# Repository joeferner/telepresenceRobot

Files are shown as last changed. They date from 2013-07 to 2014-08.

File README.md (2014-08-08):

Telepresence Robot
==================

After seeing a commercial for a Telepresence robot on TV, I knew I wanted to play with one, but after looking at prices I didn't want to pay for one.

I used an Android Nexus 7 tablet for the video conferencing. A custom PCB with an STM32 ARM processor and an FTDI USB chip to connect the Android tablet with the motors.

[Schematic](https://github.com/joeferner/telepresenceRobot/blob/master/hardware/main.pdf?raw=true)

Video
-----

YouTube (http://www.youtube.com/watch?v=nxQw_-PgoPo)

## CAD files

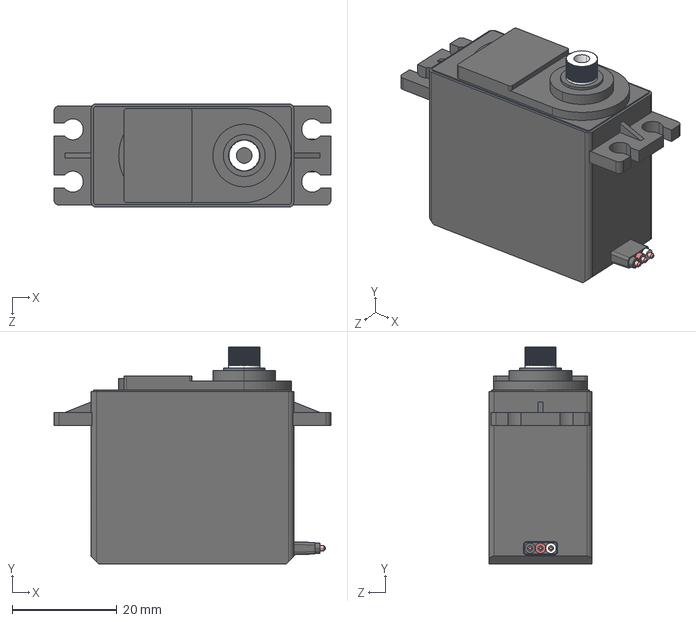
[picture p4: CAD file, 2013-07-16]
mechanical/Servo.STEP
53.0 x 41.5 x 19.8 mm

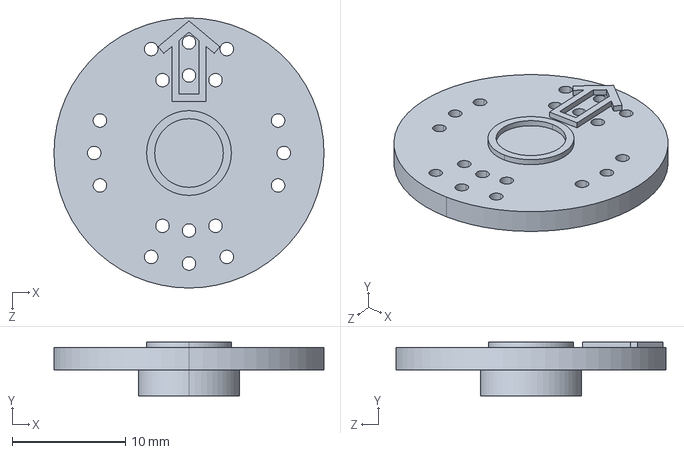
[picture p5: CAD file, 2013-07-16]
mechanical/Servo-Horn.STEP
23.9 x 4.78 x 23.9 mm

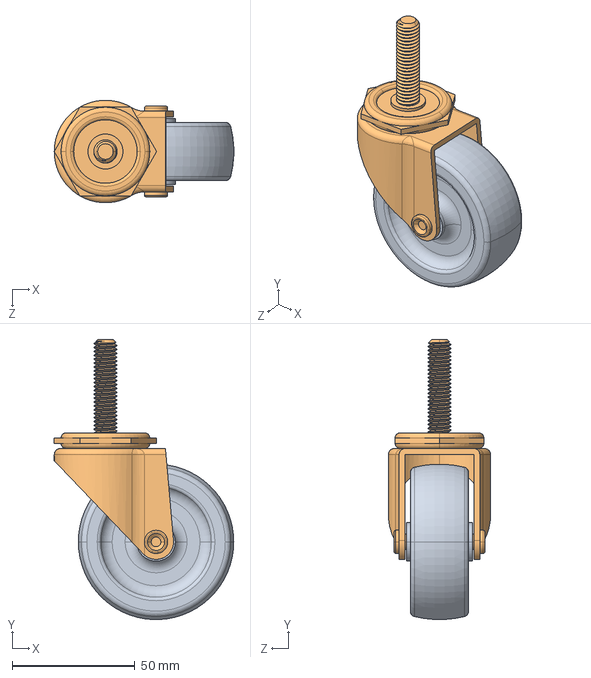
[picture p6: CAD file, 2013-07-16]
mechanical/2834T190-Threaded-Stem Swivel Caster.STEP
73.2 x 114.2 x 41.8 mm

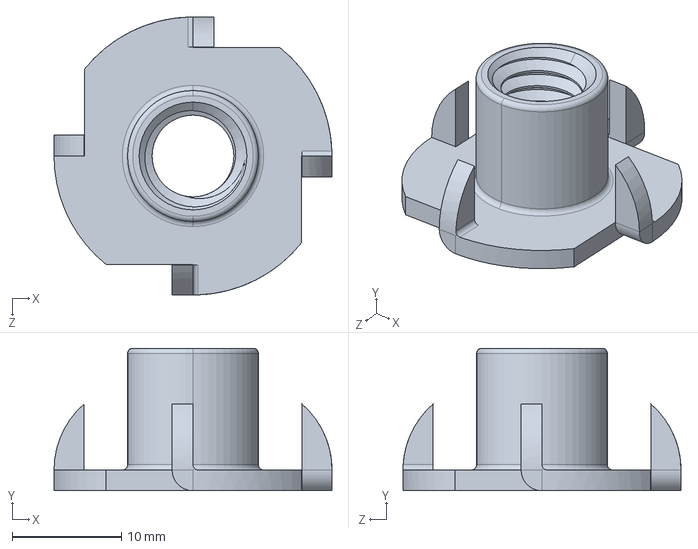
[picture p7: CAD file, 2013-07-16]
mechanical/90973A120-Stainless Steel Tee Nut.STEP
25.4 x 13.0 x 25.4 mm

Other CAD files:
mechanical/2834T190-Threaded-Stem Swivel Caster.ipt
mechanical/90973A120-Stainless Steel Tee Nut.ipt
mechanical/BatteryLatch-Latch.ipt
mechanical/BatteryLatch-Lower.ipt
mechanical/BatteryLatch-Outer.ipt
mechanical/BatteryLatch-Spring.ipt
mechanical/BatteryLatch.iam
mechanical/CircuitBoard.ipt
mechanical/Ground.ipt
mechanical/HD-BK-IG-MotorBracket.ipt
mechanical/Human_5ft_9in.ipt
mechanical/IG32P-Motor.ipt
mechanical/Imported Components/Servo/Servo.ipt
mechanical/MainAssembly.iam
mechanical/MotorShroud.ipt
mechanical/MotorWheelAssembly.iam
mechanical/Nexus7.ipt
mechanical/Robot-Base-BatteryBack.ipt
mechanical/Robot-Base-Mast-Support.ipt
mechanical/Robot-Base-Support.ipt
mechanical/Robot-Battery-Rails.ipt
mechanical/Robot-Lower-Base.idw
mechanical/Robot-Lower-Base.ipt
mechanical/Robot-Mast.ipt
mechanical/Robot-Upper-Base.ipt
mechanical/Servo-Horn.ipt
mechanical/Servo.ipt
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

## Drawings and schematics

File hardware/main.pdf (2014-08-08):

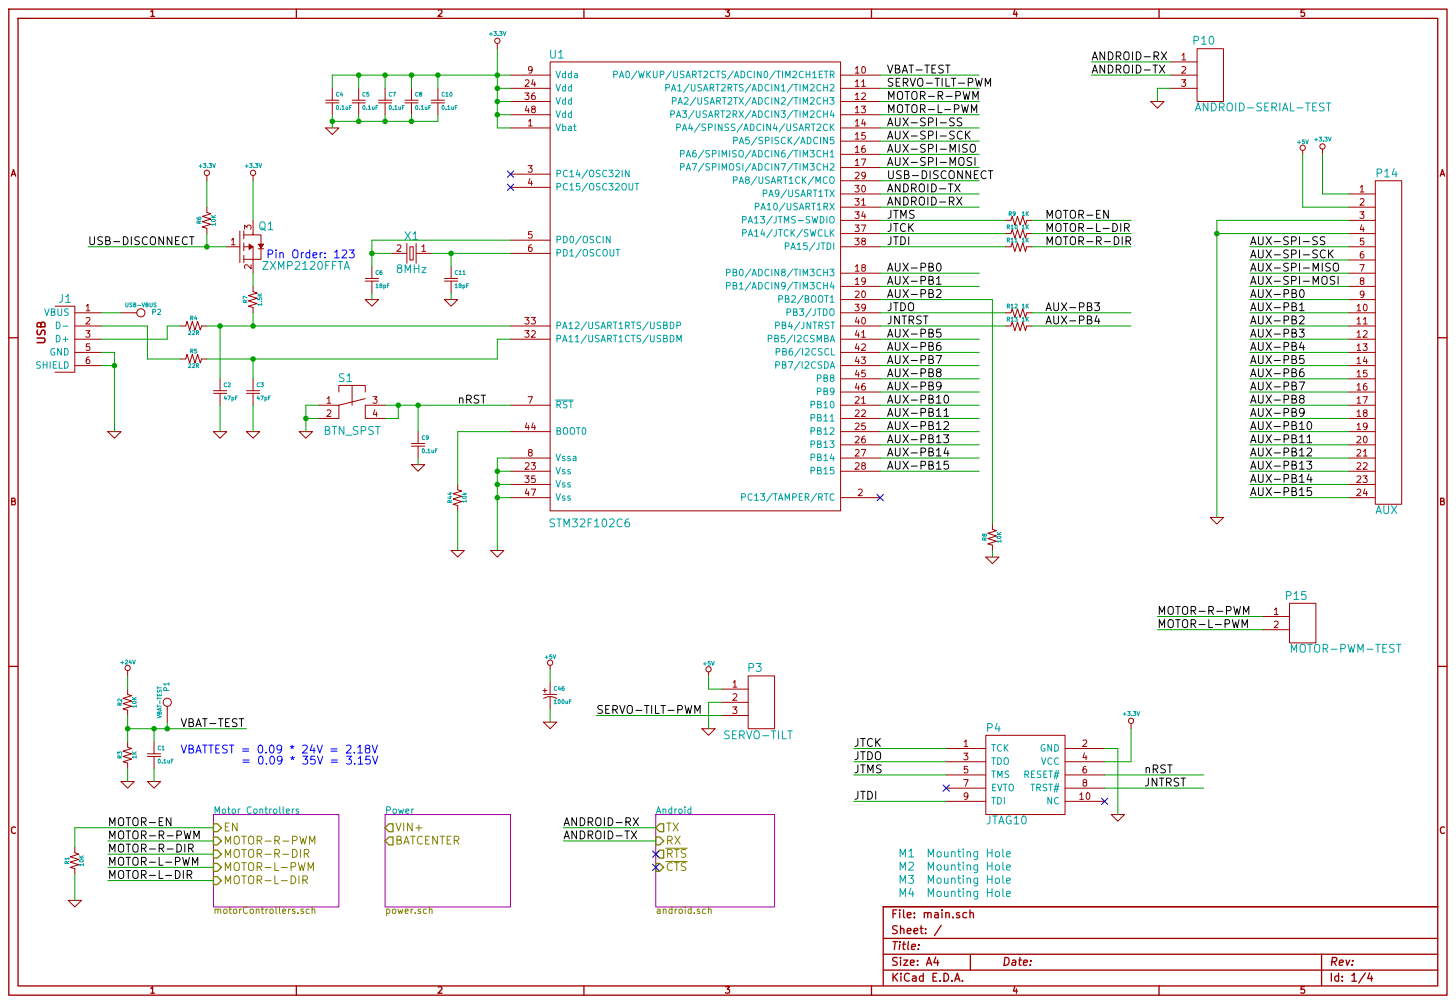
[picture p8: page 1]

3 P10 ANDROID-SERIAL-TEST
ANDROID-TX
ANDROID-RX
AUX-PB0 AUX-PB1 AUX-PB2 AUX-PB5 AUX-PB6 AUX-PB7 AUX-PB8 AUX-PB9 AUX-PB10 AUX-PB11 AUX-PB12 AUX-PB13 AUX-PB14 AUX-PB15
nRST AUX-PB4

19 P14 AUX
AUX-SPI-MOSI AUX-PB0 AUX-PB1 AUX-PB2 AUX-PB3 AUX-PB4 AUX-PB5 AUX-PB6 AUX-PB7 AUX-PB8 AUX-PB9 AUX-PB10 AUX-PB11 AUX-PB12 AUX-PB13 AUX-PB14 AUX-PB15

Motor Controllers motorControllers.sch ENMOTOR-R-PWM

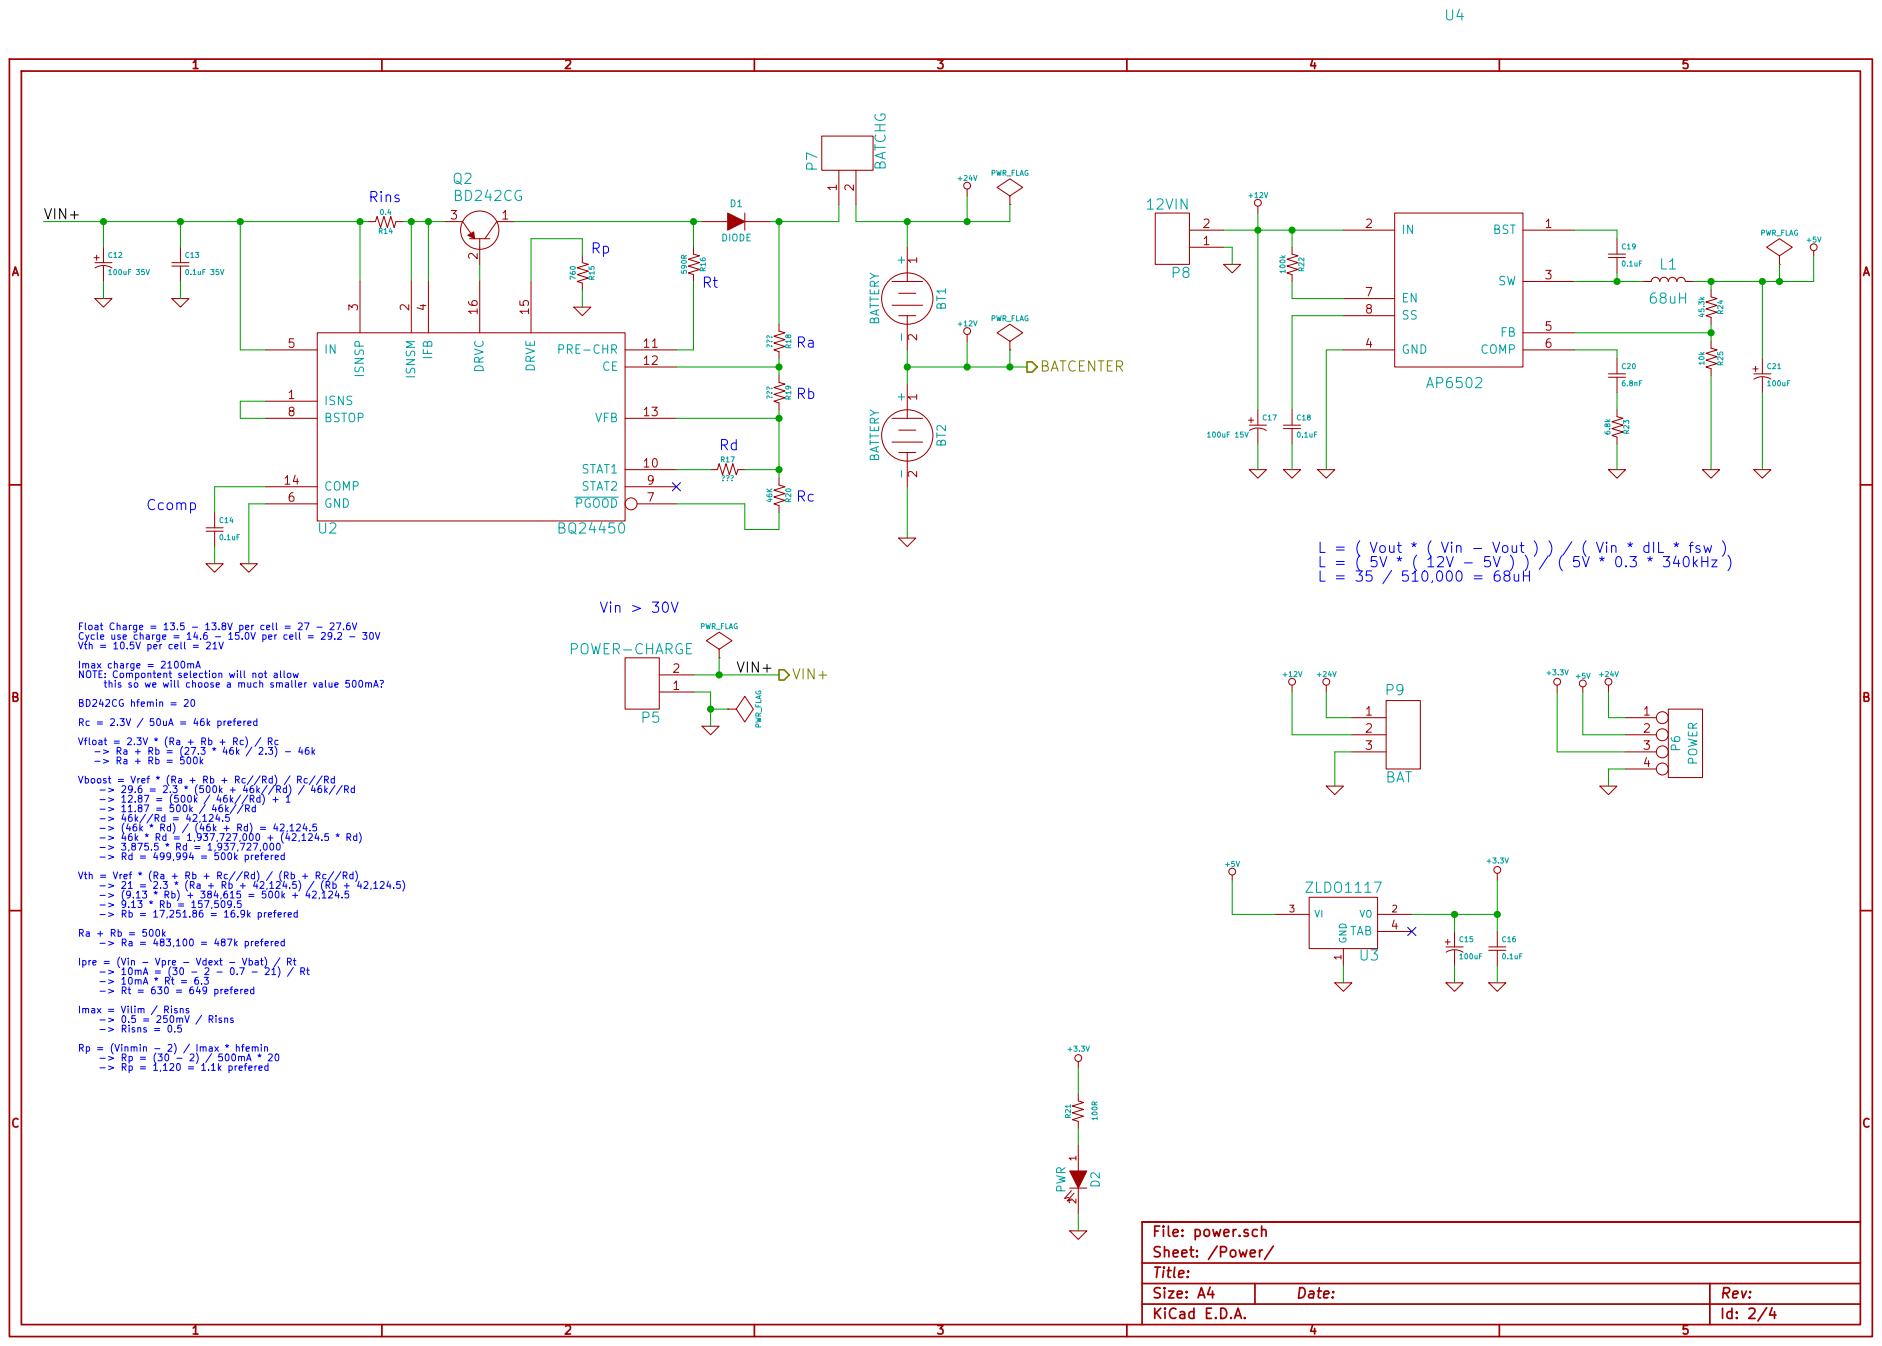
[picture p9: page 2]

L = ( Vout * ( Vin - Vout ) ) / ( Vin * dIL * fsw )
L = ( 5V * ( 12V - 5V ) ) / ( 5V * 0.3 * 340kHz )

Float Charge = 13.5 - 13.8V per cell = 27 - 27.6V Cycle use charge = 14.6 - 15.0V per cell = 29.2 - 30V
Vth = 10.5V per cell = 21V
Imax charge = 2100mA NOTE: Compontent selection will not allow
this so we will choose a much smaller value 500mA? BD242CG hfemin = 20 Rc = 2.3V / 50uA = 46k prefered Vfloat = 2.3V * (Ra + Rb + Rc) / Rc

Sheet: /Power/ VIN+ VIN+

-> Ra + Rb = 500k Vboost = Vref * (Ra + Rb + Rc//Rd) / Rc//Rd

-> Rd = 499,994 = 500k prefered Vth = Vref * (Ra + Rb + Rc//Rd) / (Rb + Rc//Rd)

-> Rb = 17,251.86 = 16.9k prefered Ra + Rb = 500k

-> Ra = 483,100 = 487k prefered
Ipre = (Vin - Vpre - Vdext - Vbat) / Rt
-> Rt = 630 = 649 prefered
Imax = Vilim / Risns
-> 0.5 = 250mV / Risns
-> Risns = 0.5 Rp = (Vinmin - 2) / Imax * hfemin

Id: 2/4 Title: File: power.sch

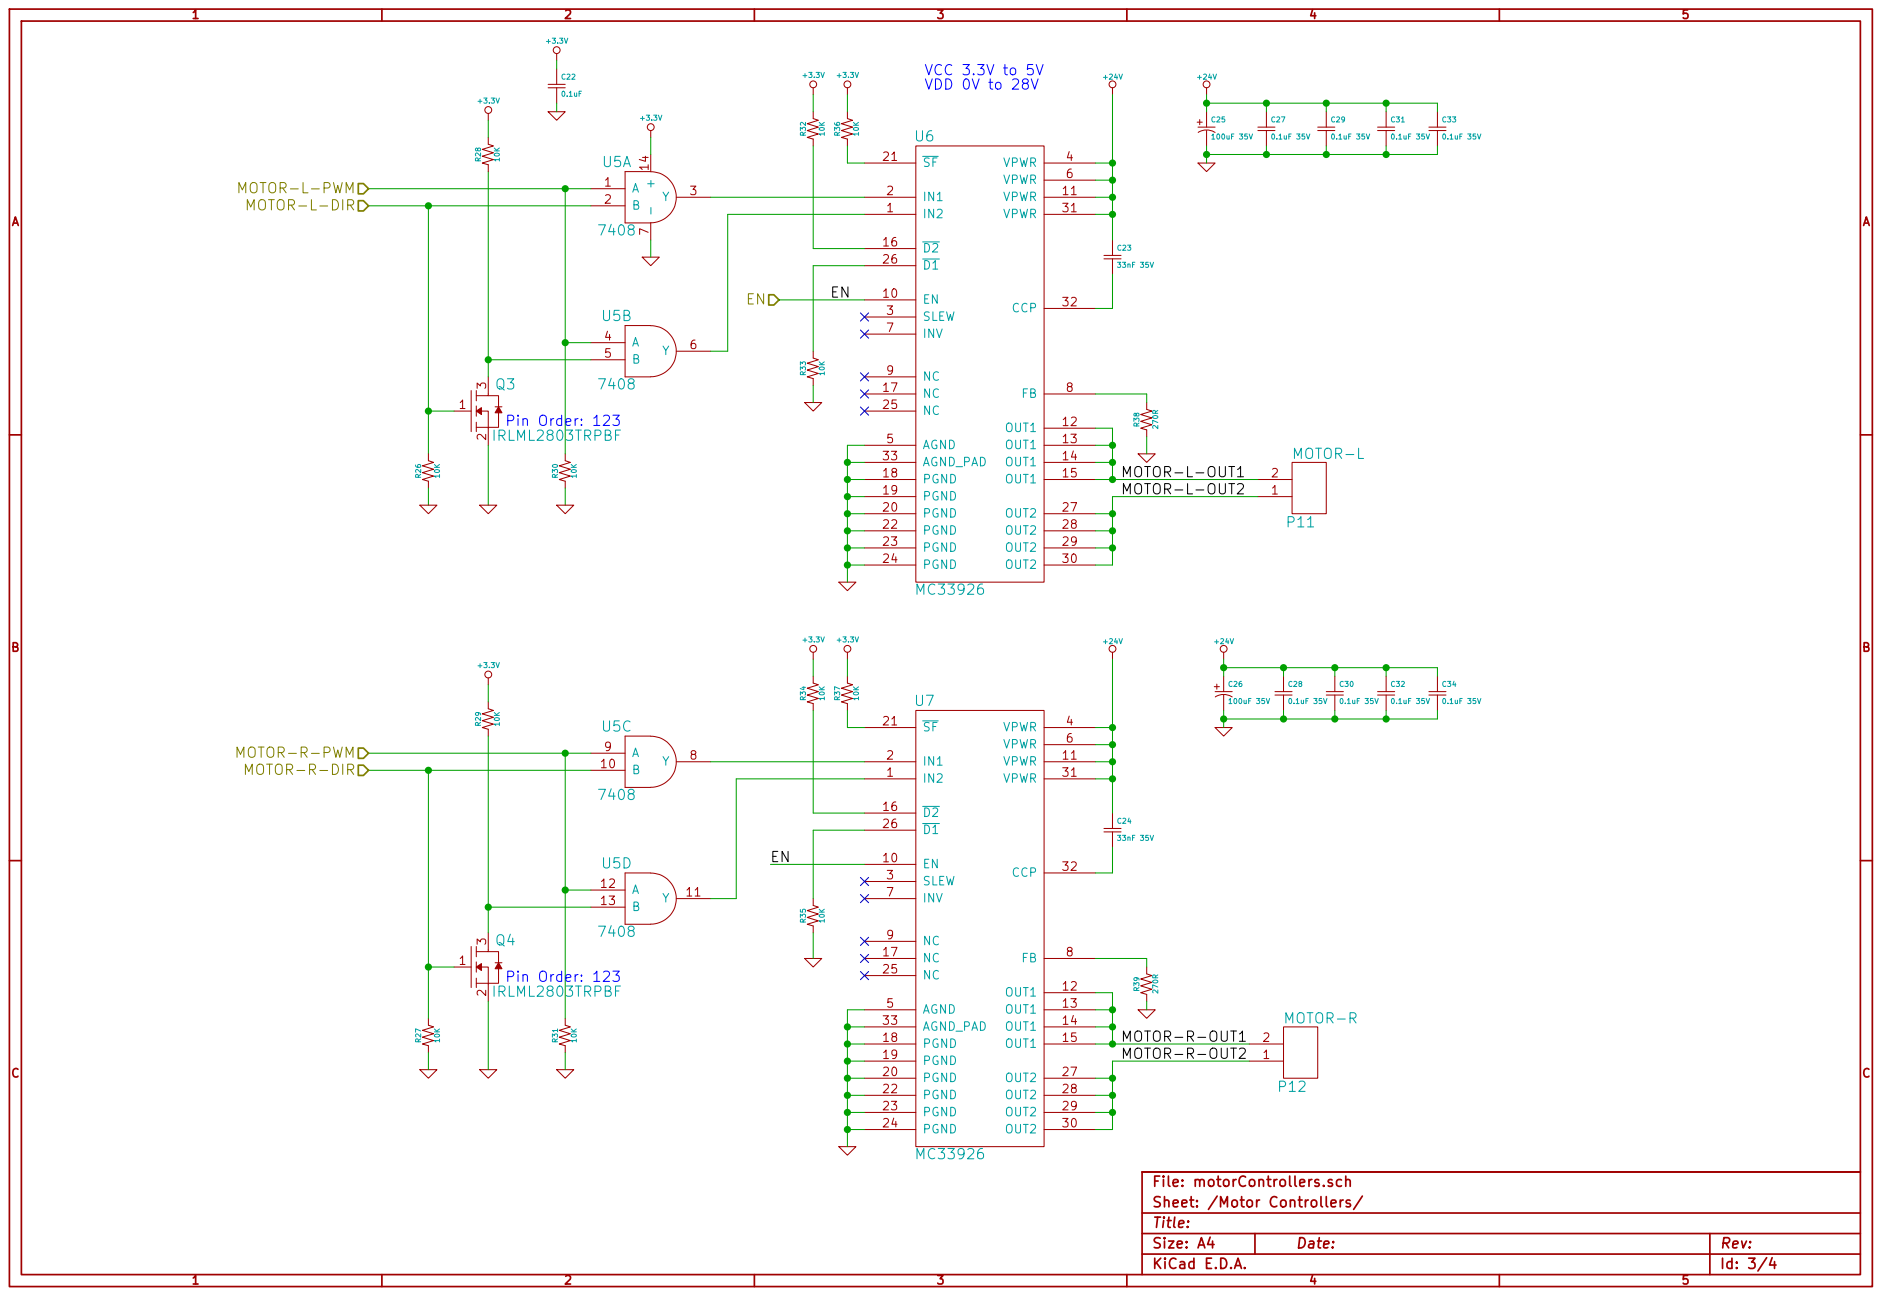
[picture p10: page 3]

Id: 3/4 Title: File: motorControllers.sch

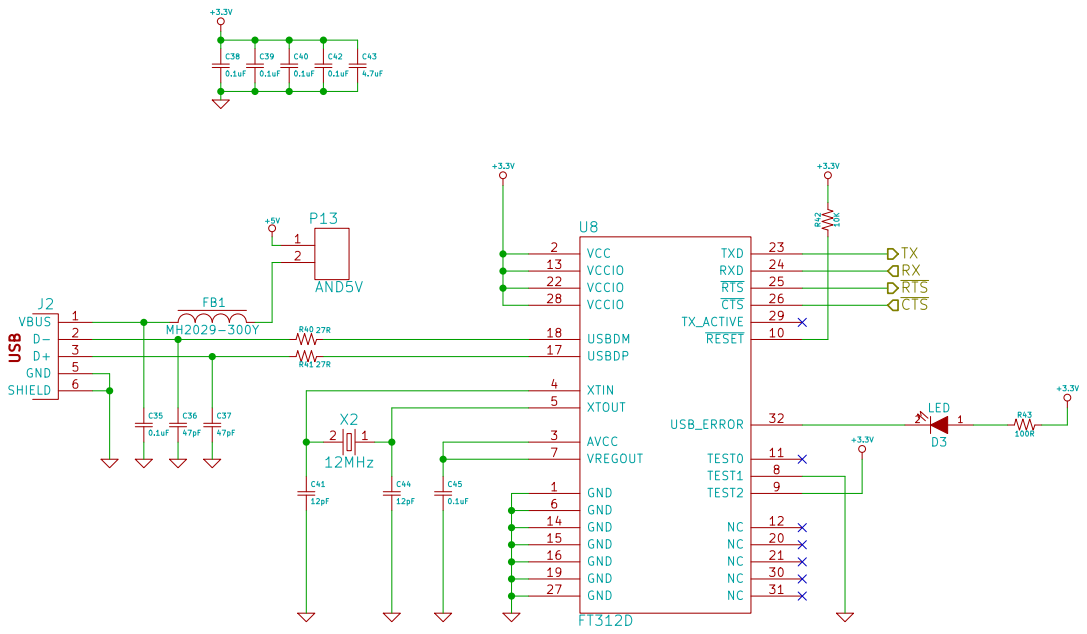
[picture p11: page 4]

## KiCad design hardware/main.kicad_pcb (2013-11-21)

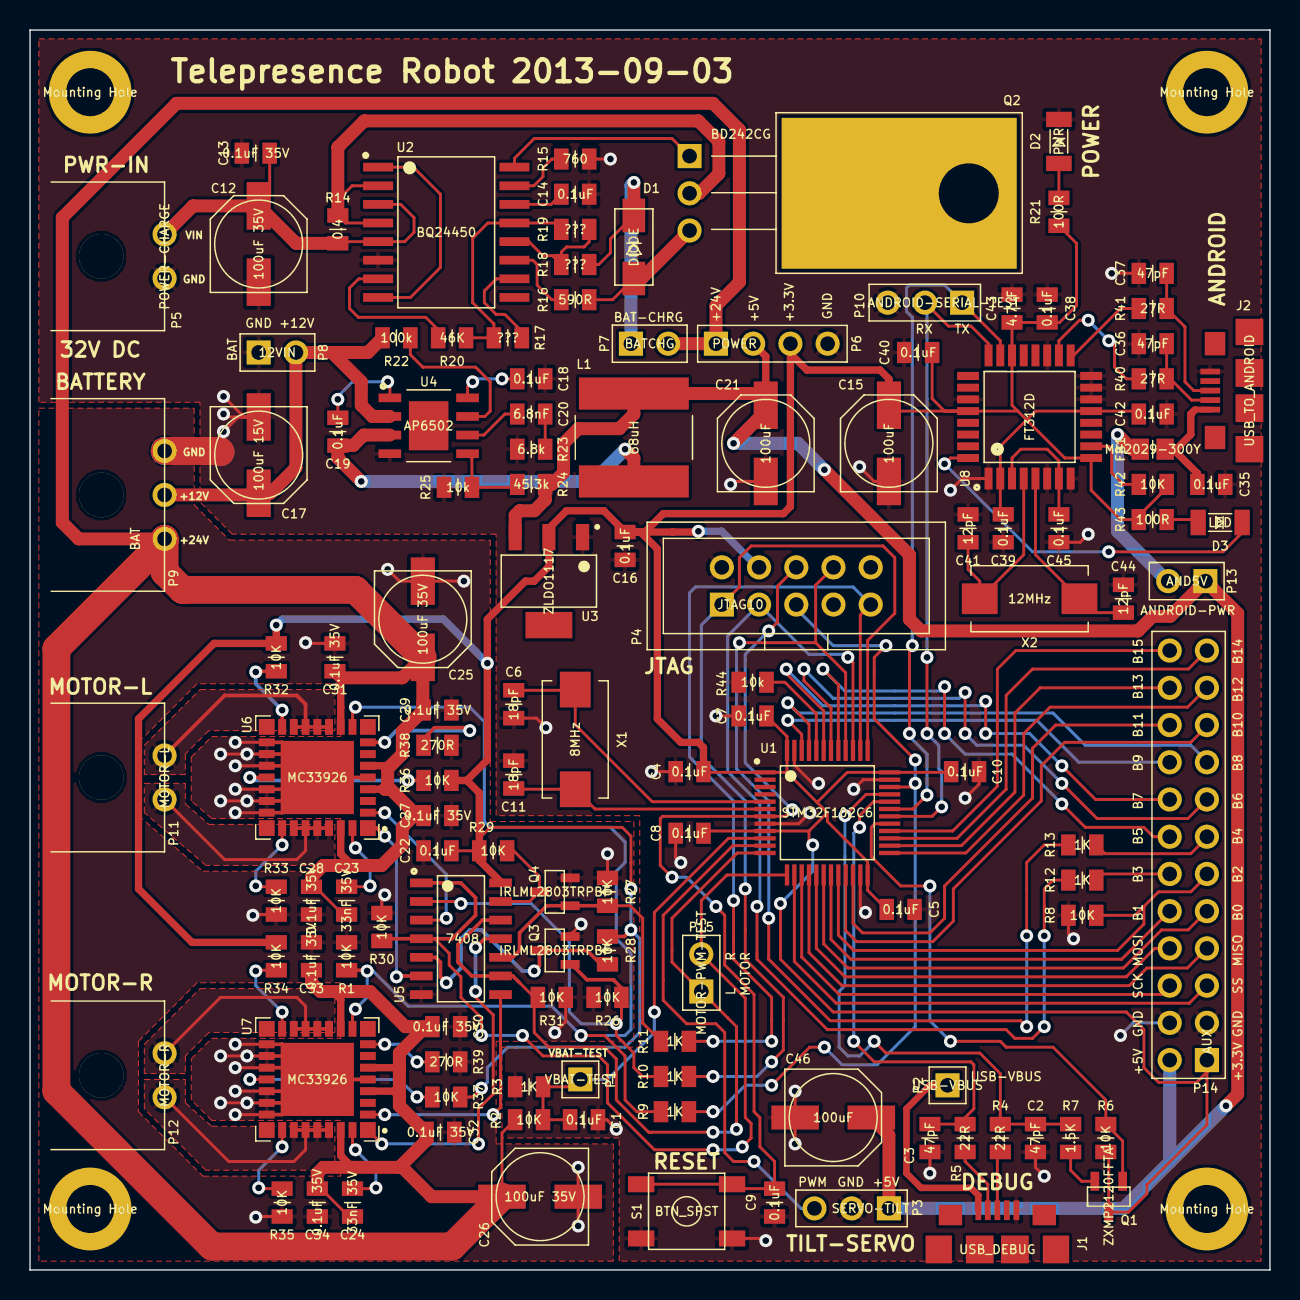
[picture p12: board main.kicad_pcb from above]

Board: 2 copper layers, 84.6 x 84.6 mm, 133 parts (0 on the bottom side), 103 nets.

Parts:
BT1, BT2: BATTERY; EMPTY
C1, C4, C5, C7, C8, C9, C10, C14, C16, C18, C19, C22, C35, C38, C39, C40, C42, C45: 0.1uF; CAPC2012X100N
C2, C3, C36, C37: 47pF; CAPC2012X100N
C6, C11: 18pF; CAPC2012X100N
C12, C25, C26: 100uF 35V; CAPAE660X790N
C13, C27, C28, C29, C30, C31, C32, C33, C34: 0.1uF 35V; CAPC2012X100N
C15, C21, C46: 100uF; CAPAE660X790N
C17: 100uF 15V; CAPAE660X790N
C20: 6.8nF; CAPC2012X100N
C23, C24: 33nF 35V; CAPC2012X100N
C41, C44: 12pF; CAPC2012X100N
C43: 4.7uF; CAPC2012X100N
D1: DIODE; DIOM5226X220N
D2: PWR; LEDC3216X100N
D3: LED; LEDC3216X100N
FB1: MH2029-300Y; INDC2012X110N
J1: USB_DEBUG; JST_UB-MC5BR3-SD204-4S-NMP
J2: USB_TO_ANDROID; JST_UB-MC5BR3-SD204-4S-NMP
L1: 68uH; IND_ASPI-8040S-680M-T
M1, M2, M3, M4: Mounting Hole; MTGNP565H328Z565P
P1: VBAT-TEST; HDRV1W66P254_1X1_254X249X838P
P2: USB-VBUS; HDRV1W66P254_1X1_254X249X838P
P3: SERVO-TILT; HDRV3W66P254_1X3_762X249X838P
P4: JTAG10; SHDRV10W66P254_2X5_2035X870X609P
P5: POWER-CHARGE; TECONN-2-1445098-2
P6: POWER; HDRV4W66P254_1X4_1016X249X838P
P7: BATCHG; HDRV2W66P254_1X2_508X249X838P
P8: 12VIN; HDRV2W66P254_1X2_508X249X838P
P9: BAT; TECONN-2-1445098-3
P10: ANDROID-SERIAL-TEST; HDRV3W66P254_1X3_762X249X838P
P11: MOTOR-L; TECONN-2-1445098-2
P12: MOTOR-R; TECONN-2-1445098-2
P13: AND5V; HDRV2W66P254_1X2_508X249X838P
P14: AUX; HDRV24W66P254_2X12_3048X503X838P
P15: MOTOR-PWM-TEST; HDRV2W66P254_1X2_508X249X838P
Q1: ZXMP2120FFTA; SOT95P237X112_123-3N
Q2: BD242CG; TO254P1512X997X450-231-3P
Q3, Q4: IRLML2803TRPBF; SOT95P237X112_123-3N
R1, R2, R6, R8, R26, R27, R28, R29, R30, R31, R32, R33, R34, R35, R36, R37, R42: 10K; RESC2012X100N
R3, R9, R10, R11, R12, R13: 1K; RESC2012X100N
R4, R5: 22R; RESC2012X100N
R7: 1.5K; RESC2012X100N
R14: 0.4; RESC2012X100N
R15: 760; RESC2012X100N
R16: 590R; RESC2012X100N
R17, R18, R19: ???; RESC2012X100N
R20: 46K; RESC2012X100N
R21, R43: 100R; RESC2012X100N
R22: 100k; RESC2012X100N
R23: 6.8k; RESC2012X100N
R24: 45.3k; RESC2012X100N
R25, R44: 10k; RESC2012X100N
R38, R39: 270R; RESC2012X100N
R40, R41: 27R; RESC2012X100N
S1: BTN_SPST; CKCOMP-PTS525SM10SMTR
U1: STM32F102C6; QFP50P900X900X160-48N
U2: BQ24450; SOIC127P1030X265-16N
U3: ZLDO1117; SOT230P700X180-4N
U4: AP6502; SOIC127P600X150-9N
U5: 7408; SOIC127P600X175-14N
U6, U7: MC33926; PQFN80P800X800X220-33N
U8: FT312D; QFP80P900X900X160-32N
X1: 8MHz; XTAL8045X200N
X2: 12MHz; XTAL8045X200N

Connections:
+3.3V: C4.1, C5.1, C7.1, C8.1, C10.1, C15.1, C16.1, C22.1, C38.1, C39.1, C40.1, C42.1, C43.1, P4.4, P6.3, P14.1, Q1.3, R6.1, R21.1, R28.1, R29.1, R32.1, R34.1, R36.1, R37.1, R42.1, R43.1, U1.1, U1.9, U1.24, U1.36, U1.48, U3.2, U5.14, U8.2, U8.9, U8.13, U8.22, U8.28
+5V: C21.1, C46.1, L1.1, P3.1, P6.2, P13.1, P14.2, R24.2, U3.3
+12V: C17.1, P8.2, P9.2, R22.2, U4.2
+24V: C23.1, C24.1, C25.1, C26.1, C27.1, C28.1, C29.1, C30.1, C31.1, C32.1, C33.1, C34.1, P6.1, P7.2, P9.1, R2.1, U6.4, U6.6, U6.11, U6.31, U7.4, U7.6, U7.11, U7.31
/AUX-PB0: P14.9, U1.18
/AUX-PB1: P14.10, U1.19
/AUX-PB2: P14.11, R8.1, U1.20
/AUX-PB3: P14.12, R12.2
/AUX-PB4: P14.13, R13.2
/AUX-PB5: P14.14, U1.41
/AUX-PB6: P14.15, U1.42
/AUX-PB7: P14.16, U1.43
/AUX-PB8: P14.17, U1.45
/AUX-PB9: P14.18, U1.46
/AUX-PB10: P14.19, U1.21
/AUX-PB11: P14.20, U1.22
/AUX-PB12: P14.21, U1.25
/AUX-PB13: P14.22, U1.26
/AUX-PB14: P14.23, U1.27
/AUX-PB15: P14.24, U1.28
/AUX-SPI-MISO: P14.7, U1.16
/AUX-SPI-MOSI: P14.8, U1.17
/AUX-SPI-SCK: P14.6, U1.15
/AUX-SPI-SS: P14.5, U1.14
/Android/RX: P10.2, U1.30, U8.24
/Android/TX: P10.1, U1.31, U8.23
/JNTRST: P4.8, R13.1, U1.40
/JTCK: P4.1, R10.1, U1.37
/JTDI: P4.9, R11.1, U1.38
/JTDO: P4.3, R12.1, U1.39
/JTMS: P4.5, R9.1, U1.34
/Motor Controllers/EN: R1.1, R9.2, U6.10, U7.10
/Motor Controllers/MOTOR-L-DIR: Q3.1, R10.2, R26.1, U5.2
/Motor Controllers/MOTOR-L-OUT1: P11.2, U6.12, U6.13, U6.14, U6.15
/Motor Controllers/MOTOR-L-OUT2: P11.1, U6.27, U6.28, U6.29, U6.30
/Motor Controllers/MOTOR-L-PWM: P15.2, R30.1, U1.13, U5.1, U5.4
/Motor Controllers/MOTOR-R-DIR: Q4.1, R11.2, R27.1, U5.10
/Motor Controllers/MOTOR-R-OUT1: P12.2, U7.12, U7.13, U7.14, U7.15
/Motor Controllers/MOTOR-R-OUT2: P12.1, U7.27, U7.28, U7.29, U7.30
/Motor Controllers/MOTOR-R-PWM: P15.1, R31.1, U1.12, U5.9, U5.12
/Power/VIN+: C12.1, C13.1, P5.2, R14.1, U2.3, U2.5
/SERVO-TILT-PWM: P3.3, U1.11
/USB-DISCONNECT: Q1.1, R6.2, U1.29
/VBAT-TEST: C1.1, P1.1, R2.2, R3.1, U1.10
/nRST: C9.1, P4.6, S1.3, S1.4, U1.7
GND: C1.2, C2.2, C3.2, C4.2, C5.2, C6.2, C7.2, C8.2, C9.2, C10.2, C11.2, C12.2, C13.2, C14.2, C15.2, C16.2, C17.2, C18.2, C21.2, C22.2, C25.2, C26.2, C27.2, C28.2, C29.2, C30.2, C31.2, C32.2, C33.2, C34.2, C35.2, C36.2, C37.2, C38.2, C39.2, C40.2, C41.2, C42.2, C43.2, C44.2, C45.2, C46.2, D2.2, J1.5, J2.5, P3.2, P4.2, P5.1, P6.4, P8.1, P9.3, P10.3, P14.3, P14.4, Q3.2, Q4.2, R1.2, R3.2, R8.2, R15.1, R23.1, R25.1, R26.2, R27.2, R30.2, R31.2, R33.2, R35.2, R38.2, R39.2, R44.2, S1.1, S1.2, U1.8, U1.23, U1.35, U1.47, U2.6, U3.1, U4.4, U5.7, U6.5, U6.18, U6.19, U6.20, U6.22, U6.23, U6.24, U6.33, U7.5, U7.18, U7.19, U7.20, U7.22, U7.23, U7.24, U7.33, U8.1, U8.6, U8.8, U8.14, U8.15, U8.16, U8.19, U8.27
unnamed: C2.1, R4.1, R7.2, U1.33
unnamed: C3.1, R5.1, U1.32
unnamed: C6.1, U1.5, X1.2
unnamed: C11.1, U1.6, X1.1
unnamed: C14.1, U2.14
unnamed: C18.1, U4.8
unnamed: C19.1, U4.1
unnamed: C19.2, L1.2, U4.3
unnamed: C20.1, U4.6
unnamed: C20.2, R23.2
unnamed: C23.2, U6.32
unnamed: C24.2, U7.32
unnamed: C35.1, FB1.1, J2.1
unnamed: C36.1, J2.2, R40.2
unnamed: C37.1, J2.3, R41.2
unnamed: C41.1, U8.4, X2.2
unnamed: C44.1, U8.5, X2.1
unnamed: C45.1, U8.3, U8.7
unnamed: D1.1, Q2.1, R16.2
unnamed: D1.2, P7.1, R18.2
unnamed: D2.1, R21.2
unnamed: D3.1, R43.2
unnamed: D3.2, U8.32
unnamed: FB1.2, P13.2
unnamed: J1.1, P2.1
unnamed: J1.2, R5.2
unnamed: J1.3, R4.2
unnamed: Q1.2, R7.1
unnamed: Q2.2, U2.16
unnamed: Q2.3, R14.2, U2.2, U2.4
unnamed: Q3.3, R28.2, U5.5
unnamed: Q4.3, R29.2, U5.13
unnamed: R15.2, U2.15
unnamed: R16.1, U2.11
unnamed: R17.1, R19.1, R20.2, U2.13
unnamed: R17.2, U2.10
unnamed: R18.1, R19.2, U2.12
unnamed: R20.1, U2.7
unnamed: R22.1, U4.7
unnamed: R24.1, R25.2, U4.5
unnamed: R32.2, U6.16
unnamed: R33.1, U6.26
unnamed: R34.2, U7.16
unnamed: R35.1, U7.26
unnamed: R36.2, U6.21
unnamed: R37.2, U7.21
unnamed: R38.1, U6.8
unnamed: R39.1, U7.8
unnamed: R40.1, U8.18
unnamed: R41.1, U8.17
unnamed: R42.2, U8.10
unnamed: R44.1, U1.44
unnamed: U2.1, U2.8
unnamed: U5.3, U6.2
unnamed: U5.6, U6.1
unnamed: U5.8, U7.2
unnamed: U5.11, U7.1

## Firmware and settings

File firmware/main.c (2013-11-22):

#include "delay.h"
#include "debug.h"
#include "android.h"
#include "battery_voltage.h"
#include "usb.h"
#include "ring_buffer.h"
#include "util.h"
#include "time.h"
#include "motor.h"
#include <misc.h>
#include <string.h>

#include <stm32f10x_gpio.h>

typedef struct {
  volatile int16_t speedLeft;
  volatile int16_t speedRight;
  volatile int16_t targetSpeedLeft;
  volatile int16_t targetSpeedRight;
  volatile uint32_t targetSpeedLastUpdated;
} RobotRegisters;

#define INPUT_BUFFER_SIZE 100
uint8_t input_buffer[INPUT_BUFFER_SIZE];
ring_buffer input_ring_buffer;
RobotRegisters robot_registers;
uint32_t last_update_speed = 0;
uint32_t last_update_battery_voltage = 0;
uint32_t servo_tilt_end_time = 0;
uint8_t servo_tilt_on = TRUE;

void disable_jtag();
void loop();
void init_robot_registers();
void process_input(uint8_t* data, uint16_t len);
void process_input_line(char* line);
void process_set_command(char* line);
void process_get_command(char* line);
void process_connect_command(char* line);
int8_t parse_speed(const char* str);
void set_speed(int16_t speedLeft, int16_t speedRight);
void update_speed();
void update_battery_voltage();
void update_servo_tilt();

int main(void) {
  // Configure the NVIC Preemption Priority Bits
  // 2 bit for pre-emption priority, 2 bits for subpriority
  NVIC_PriorityGroupConfig(NVIC_PriorityGroup_2);

  ring_buffer_init(&input_ring_buffer, input_buffer, INPUT_BUFFER_SIZE);

  debug_led_config();

  android_config();
  delay_ms(1000); // !!!! IMPORTANT: Keep this line in here. If we have a JTAG issue we need this time to get in before JTAG is disabled.
  print_info("BEGIN Init\n");
  disable_jtag();
  init_robot_registers();
  motor_config();
  time_config();
  //usb_config();
  battery_voltage_config();
  print_info("END Init\n");

  servo_tilt_end_time = time_ms();
  servo_tilt_set(0x60);
  motor_enable(TRUE);
  while (1) {
    loop();
  }
  return 0;
}

void loop() {
  update_speed();
  update_battery_voltage();
  update_servo_tilt();
}

void update_servo_tilt() {
  if(servo_tilt_on && time_ms() > servo_tilt_end_time) {
    servo_tilt_stop();
    servo_tilt_on = FALSE;
  }
}

void update_battery_voltage() {
  if ((time_ms() - last_update_battery_voltage) < 1000) {
    return;
  }

  uint32_t v = battery_voltage_read();
  print_info("batteryVoltage: ");
  print_u32(v, 16);
  print("\n");

  last_update_battery_voltage = time_ms();
}

void update_speed() {
  if ((time_ms() - last_update_speed) < 100) {
    return;
  }

  // this timeout is for safety. If we haven't received a speed update in over x seconds we should stop the robot
  if ((time_ms() - robot_registers.targetSpeedLastUpdated) > 10000) {
    set_speed(0, 0);
  }

  // provide for acceleration and deceleration
  if (robot_registers.targetSpeedLeft > robot_registers.speedLeft) {
    robot_registers.speedLeft += min(10, robot_registers.targetSpeedLeft - robot_registers.speedLeft);
  } else if (robot_registers.targetSpeedLeft < robot_registers.speedLeft) {
    robot_registers.speedLeft -= min(10, robot_registers.speedLeft - robot_registers.targetSpeedLeft);
  }

  if (robot_registers.targetSpeedRight > robot_registers.speedRight) {
    robot_registers.speedRight += min(10, robot_registers.targetSpeedRight - robot_registers.speedRight);
  } else if (robot_registers.targetSpeedRight < robot_registers.speedRight) {
    robot_registers.speedRight -= min(10, robot_registers.speedRight - robot_registers.targetSpeedRight);
  }

  motor_set_speed(robot_registers.speedLeft, robot_registers.speedRight);

  last_update_speed = time_ms();
}

void disable_jtag() {
  GPIO_PinRemapConfig(GPIO_Remap_SWJ_Disable, ENABLE);
}

void init_robot_registers() {
  robot_registers.speedLeft = 0;
  robot_registers.speedRight = 0;
  robot_registers.targetSpeedLeft = 0;
  robot_registers.targetSpeedRight = 0;
}

void android_on_rx(uint8_t* data, uint16_t len) {
  process_input(data, len);
}

void usb_on_rx(uint8_t* data, uint16_t len) {
  process_input(data, len);
}

void process_input(uint8_t* data, uint16_t len) {
#define MAX_LINE_LENGTH 100
  char line[MAX_LINE_LENGTH];

  ring_buffer_write(&input_ring_buffer, data, len);
  while (ring_buffer_readline(&input_ring_buffer, line, MAX_LINE_LENGTH) > 0) {
    trim_right(line);
    process_input_line(line);
  }
}

void process_input_line(char* line) {
  print_info("");
  print(line);
  print("\n");

  if (starts_with(line, "connect")) {
    process_connect_command(line);
  } else if (starts_with(line, "set ")) {
    process_set_command(line);
  } else if (starts_with(line, "get ")) {
    process_get_command(line);
  } else {
    print_fail("Invalid command: ");
    print(line);
    print("\n");
  }
}

void process_connect_command(char* line) {
  print_success("OK\n");
}

void process_set_command(char* line) {
  char* p = line + strlen("set ");
  char* eq = strchr(line, '=');
  if (eq) {
    char* val = eq + 1;
    *eq = '\0';
    if (!strcmp(p, "speed")) {
      int8_t speedLeft = parse_speed(val);
      int8_t speedRight = parse_speed(val + 2);
      set_speed(speedLeft, speedRight);
      print_success("OK ");
      print_8(speedLeft, 10);
      print(", ");
      print_8(speedRight, 10);
      print("\n");
    } else if (!strcmp(p, "tilt")) {
      uint8_t tilt = parse_hex8(val);
      servo_tilt_on = TRUE;
      servo_tilt_end_time = time_ms() + 3000;
      servo_tilt_set(tilt);
      print_success("OK ");
      print_u8(tilt, 16);
      print("\n");
    } else {
      print_fail("Invalid set variable '");
      print(p);
      print("'\n");
    }
  } else {
    print_fail("Invalid set, no '='\n");
  }
}

void process_get_command(char* line) {
  char* p = line + strlen("get ");
  if (!strcmp(p, "speed")) {
    print_success("OK ");
    print_u8(robot_registers.speedLeft, 16);
    print_u8(robot_registers.speedRight, 16);
    print("\n");
  } else if (!strcmp(p, "target_speed")) {
    print_success("OK ");
    print_u8(robot_registers.targetSpeedLeft, 16);
    print_u8(robot_registers.targetSpeedRight, 16);
    print("\n");
  } else {
    print_fail("Invalid get variable '");
    print(p);
    print("'\n");
  }
}

void set_speed(int16_t targetSpeedLeft, int16_t targetSpeedRight) {
  robot_registers.targetSpeedLeft = targetSpeedLeft;
  robot_registers.targetSpeedRight = targetSpeedRight;
  robot_registers.targetSpeedLastUpdated = time_ms();
}

/**
 * Speed is encoded using a single byte.
 * @param str String containing a hex byte string
 * @return the speed from -128 to 128
 */
int8_t parse_speed(const char* str) {
  return parse_hex8(str);
}

void assert_failed(uint8_t* file, uint32_t line) {
  print_error("assert_failed: file ");
  print((const char*) file);
  print(" on line ");
  print_u32(line, 10);
  print("\n");

  /* Infinite loop */
  while (1) {
    delay_ms(100);
  }
}

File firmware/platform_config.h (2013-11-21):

#ifndef __PLATFORM_CONFIG_H
#define __PLATFORM_CONFIG_H

#include <stm32f10x.h>
#include <stm32f10x_gpio.h>
#include <stm32f10x_exti.h>
#include <stm32f10x_pwr.h>
#include <stm32f10x_rcc.h>
#include <stm32f10x_adc.h>
#include <usb_lib.h>

#define ID1                    (0x1FFFF7E8)
#define ID2                    (0x1FFFF7EC)
#define ID3                    (0x1FFFF7F0)

#define DEBUG_LED              GPIOB
#define DEBUG_LED_PIN          GPIO_Pin_0
#define DEBUG_LED_RCC          RCC_APB2Periph_GPIOB

#define USB_DISCONNECT         GPIOA
#define USB_DISCONNECT_PIN     GPIO_Pin_8
#define USB_DISCONNECT_RCC     RCC_APB2Periph_GPIOA

#define BATTERY_VOLTAGE        GPIOA
#define BATTERY_VOLTAGE_PIN    GPIO_Pin_0
#define BATTERY_VOLTAGE_RCC    RCC_APB2Periph_GPIOA
#define BATTERY_VOLTAGE_ADC_CH ADC_Channel_0

#define MOTOR_PWM_TIMER_RCC    RCC_APB1Periph_TIM2

#define MOTOR_EN               GPIOA
#define MOTOR_EN_PIN           GPIO_Pin_13
#define MOTOR_EN_RCC           RCC_APB2Periph_GPIOA

#define MOTOR_LEFT_DIR         GPIOA
#define MOTOR_LEFT_DIR_PIN     GPIO_Pin_14
#define MOTOR_LEFT_DIR_RCC     RCC_APB2Periph_GPIOA

// TIM2_CH3
#define MOTOR_LEFT_PWM         GPIOA
#define MOTOR_LEFT_PWM_PIN     GPIO_Pin_3
#define MOTOR_LEFT_PWM_RCC     RCC_APB2Periph_GPIOA | RCC_APB2Periph_AFIO

#define MOTOR_RIGHT_DIR        GPIOA
#define MOTOR_RIGHT_DIR_PIN    GPIO_Pin_15
#define MOTOR_RIGHT_DIR_RCC    RCC_APB2Periph_GPIOA

// TIM2_CH4
#define MOTOR_RIGHT_PWM        GPIOA
#define MOTOR_RIGHT_PWM_PIN    GPIO_Pin_2
#define MOTOR_RIGHT_PWM_RCC    RCC_APB2Periph_GPIOA | RCC_APB2Periph_AFIO

// TIM2_CH2
#define SERVO_TILT_PWM         GPIOA
#define SERVO_TILT_PWM_PIN     GPIO_Pin_1
#define SERVO_TILT_PWM_RCC     RCC_APB2Periph_GPIOA | RCC_APB2Periph_AFIO

#define DEBUG_USART            USART1
#define DEBUG_USART_BAUD       9600
#define DEBUG_USART_IRQ        USART1_IRQn
#define DEBUG_USART_RCC        RCC_APB2Periph_GPIOA | RCC_APB2Periph_AFIO | RCC_APB2Periph_USART1
#define DEBUG_USART_TX         GPIOA
#define DEBUG_USART_TX_PIN     GPIO_Pin_9
#define DEBUG_USART_RX         GPIOA
#define DEBUG_USART_RX_PIN     GPIO_Pin_10

#endif /* __PLATFORM_CONFIG_H */

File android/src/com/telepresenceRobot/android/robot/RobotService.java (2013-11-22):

package com.telepresenceRobot.android.robot;

import android.app.IntentService;
import android.content.Context;
import android.content.Intent;
import android.content.IntentFilter;
import android.support.v4.content.LocalBroadcastManager;
import android.util.Log;
import com.telepresenceRobot.android.Constants;
import com.telepresenceRobot.android.StatusBroadcast;
import com.telepresenceRobot.android.util.ByteUtil;

import java.io.IOException;
import java.util.Arrays;
import java.util.LinkedList;
import java.util.Queue;
import java.util.regex.Matcher;
import java.util.regex.Pattern;

public class RobotService extends IntentService {
    private static final String LOG_TAG = Constants.getLogTag(RobotService.class);
    private static final Pattern BATTERY_VOLTAGE = Pattern.compile("^\\?batteryVoltage: ([0-9a-fA-F]+)$");
    private static final int BAUD = 9600;
    private static final byte DATA_BITS = 8;
    private static final byte STOP_BITS = 1;
    private static final byte PARITY = 0;
    private static final byte FLOW_CONTROL = 0;
    private FT31xUARTInterface uartInterface;
    private final Queue<String> commandQueue = new LinkedList<String>();
    private boolean connecting;
    private boolean destorying;
    private Object currentLineLock = new Object();
    private StringBuilder currentLine = new StringBuilder();

    public RobotService() {
        super("robotService");
    }

    @Override
    public void onCreate() {
        destorying = false;
        super.onCreate();
        LocalBroadcastManager.getInstance(this).registerReceiver(robotBroadcastReceiver, new IntentFilter(RobotBroadcast.BROADCAST_NAME));
    }

    @Override
    public void onDestroy() {
        destorying = true;
        LocalBroadcastManager.getInstance(this).unregisterReceiver(robotBroadcastReceiver);
        try {
            Thread.sleep(1000);
            Log.i(LOG_TAG, "BEFORE destroyAccessory");
            this.uartInterface.destroyAccessory();
            Log.i(LOG_TAG, "AFTER destroyAccessory");
        } catch (Exception ex) {
            Log.e(LOG_TAG, "Could not destroy accessory", ex);
            StatusBroadcast.sendException(this, ex);
        }
        RobotBroadcast.sendDisconnected(this);
        super.onDestroy();
    }

    @Override
    protected void onHandleIntent(Intent intent) {
        destorying = false;
        try {
            uartInterface = new FT31xUARTInterface(this);

            connect();

            Log.i(LOG_TAG, "Starting robot loop");
            while (!destorying) {
                try {
                    loop();
                } catch (Exception ex) {
                    Log.e(LOG_TAG, "loop failed", ex);
                    StatusBroadcast.sendException(this, ex);
                }
            }
        } catch (Exception ex) {
            StatusBroadcast.sendException(this, ex);
            RobotBroadcast.sendDisconnected(this);
        } finally {
            Log.i(LOG_TAG, "Stopped robot loop");
        }
    }

    private void loop() throws Exception {
        loopSend();
        loopRead();
    }

    private void loopRead() throws IOException, InterruptedException {
        byte[] readBuffer = new byte[4096];
        int bytesReads = uartInterface.read(readBuffer, 0, 4096, 100);
        if (bytesReads <= 0) {
            return;
        }

        if (connecting) {
            RobotBroadcast.sendConnected(this);
            connecting = false;
        }

        try {
            byte[] data = Arrays.copyOfRange(readBuffer, 0, bytesReads);
            processData(data);
        } catch (Exception ex) {
            Log.e(LOG_TAG, "Calling eventHandler.onData", ex);
        }
        Log.d(LOG_TAG, "bytes read " + bytesReads + " " + new String(readBuffer, 0, bytesReads));
    }

    private void loopSend() throws IOException {
        synchronized (commandQueue) {
            if (commandQueue.size() > 0) {
                String cmd = commandQueue.remove() + "\n";
                if (uartInterface.isConnected()) {
                    Log.d(LOG_TAG, "Sending:" + cmd);
                    uartInterface.send(cmd.getBytes());
                }
            }
        }
    }

    private void processData(byte[] data) {
        synchronized (currentLineLock) {
            for (byte b : data) {
                if (b == '\r') {
                    continue;
                }

                if (b == '\n') {
                    processLine(currentLine.toString().trim());
                    currentLine = new StringBuilder();
                    continue;
                }

                if (b >= ' ' && b <= '~') {
                    currentLine.append((char) b);
                } else {
                    currentLine.append(String.format("\\x%02x", b));
                }
            }
        }
    }

    private void processLine(String line) {
        Matcher m = BATTERY_VOLTAGE.matcher(line);
        if (m.matches()) {
            int voltage = Integer.parseInt(m.group(1), 16);
            RobotBroadcast.sendBatteryVoltage(this, voltage);
            return;
        }

        RobotBroadcast.sendData(this, line.getBytes());
    }

    private RobotBroadcast.Receiver robotBroadcastReceiver = new RobotBroadcast.Receiver() {
        @Override
        protected void onSetSpeed(Context context, Intent intent, Speed speed) {
            super.onSetSpeed(context, intent, speed);
            setSpeed(speed.getLeftSpeed(), speed.getRightSpeed());
        }

        @Override
        protected void onSetTilt(Context context, Intent intent, double tilt) {
            super.onSetTilt(context, intent, tilt);
            setTilt(tilt);
        }

        @Override
        protected void onResume(Context context, Intent intent) {
            super.onResume(context, intent);
            connect();
        }
    };

    public void setSpeed(double speedLeft, double speedRight) {
        speedLeft = clamp(speedLeft, -1.0, 1.0);
        byte speedLeftByte = (byte) (speedLeft * (255 / 2));

        speedRight = clamp(speedRight, -1.0, 1.0);
        byte speedRightByte = (byte) (speedRight * (255 / 2));

        enqueueSetCommand(RobotRegister.SPEED, ByteUtil.byteToHex(speedLeftByte) + ByteUtil.byteToHex(speedRightByte));
    }

    public void setTilt(double tilt) {
        tilt = clamp(tilt, 0, 1.0);
        byte tiltByte = (byte) (tilt * 255);

        enqueueSetCommand(RobotRegister.TILT, ByteUtil.byteToHex(tiltByte));
    }

    private double clamp(double val, double min, double max) {
        return Math.max(Math.min(val, max), min);
    }

    private void enqueueSetCommand(RobotRegister robotRegister, String val) {
        enqueueCommand("set " + robotRegister.toString().toLowerCase() + "=" + val);
    }

    private void enqueueCommand(String cmd) {
        Log.i(LOG_TAG, "enqueueCommand: " + cmd);
        synchronized (commandQueue) {
            commandQueue.add(cmd);
        }
    }
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

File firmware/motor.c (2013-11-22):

#include "motor.h"
#include "platform_config.h"
#include "util.h"
#include <stm32f10x_tim.h>

#define PWM_PERIOD 0x2000

int16_t lastSpeedLeft = 0xff;
int16_t lastSpeedRight = 0xff;

uint32_t speed_to_pwm_compare(int16_t speed);

void motor_config() {
  GPIO_InitTypeDef GPIO_Config;
  uint16_t prescalerValue = 0;
  TIM_TimeBaseInitTypeDef TIM_TimeBaseStructure;
  TIM_OCInitTypeDef TIM_OCInitStructure;

  print_info("motor_config\n");

  RCC_APB1PeriphClockCmd(MOTOR_PWM_TIMER_RCC, ENABLE);

  // motor enable
  RCC_APB2PeriphClockCmd(MOTOR_EN_RCC, ENABLE);
  GPIO_Config.GPIO_Pin = MOTOR_EN_PIN;
  GPIO_Config.GPIO_Mode = GPIO_Mode_Out_PP;
  GPIO_Config.GPIO_Speed = GPIO_Speed_50MHz;
  GPIO_Init(MOTOR_EN, &GPIO_Config);
  GPIO_ResetBits(MOTOR_EN, MOTOR_EN_PIN);

  // motor left direction
  RCC_APB2PeriphClockCmd(MOTOR_LEFT_DIR_RCC, ENABLE);
  GPIO_Config.GPIO_Pin = MOTOR_LEFT_DIR_PIN;
  GPIO_Config.GPIO_Mode = GPIO_Mode_Out_PP;
  GPIO_Config.GPIO_Speed = GPIO_Speed_50MHz;
  GPIO_Init(MOTOR_LEFT_DIR, &GPIO_Config);
  GPIO_ResetBits(MOTOR_LEFT_DIR, MOTOR_LEFT_DIR_PIN);

  // motor right direction
  RCC_APB2PeriphClockCmd(MOTOR_RIGHT_DIR_RCC, ENABLE);
  GPIO_Config.GPIO_Pin = MOTOR_RIGHT_DIR_PIN;
  GPIO_Config.GPIO_Mode = GPIO_Mode_Out_PP;
  GPIO_Config.GPIO_Speed = GPIO_Speed_50MHz;
  GPIO_Init(MOTOR_RIGHT_DIR, &GPIO_Config);
  GPIO_ResetBits(MOTOR_RIGHT_DIR, MOTOR_RIGHT_DIR_PIN);

  // motor left pwm direction
  RCC_APB2PeriphClockCmd(MOTOR_LEFT_PWM_RCC, ENABLE);
  GPIO_Config.GPIO_Pin = MOTOR_LEFT_PWM_PIN;
  GPIO_Config.GPIO_Mode = GPIO_Mode_AF_PP;
  GPIO_Config.GPIO_Speed = GPIO_Speed_50MHz;
  GPIO_Init(MOTOR_LEFT_PWM, &GPIO_Config);

  // motor right pwm direction
  RCC_APB2PeriphClockCmd(MOTOR_RIGHT_PWM_RCC, ENABLE);
  GPIO_Config.GPIO_Pin = MOTOR_RIGHT_PWM_PIN;
  GPIO_Config.GPIO_Mode = GPIO_Mode_AF_PP;
  GPIO_Config.GPIO_Speed = GPIO_Speed_50MHz;
  GPIO_Init(MOTOR_RIGHT_PWM, &GPIO_Config);

  // servo tile pwm direction
  RCC_APB2PeriphClockCmd(SERVO_TILT_PWM_RCC, ENABLE);
  GPIO_Config.GPIO_Pin = SERVO_TILT_PWM_PIN;
  GPIO_Config.GPIO_Mode = GPIO_Mode_AF_PP;
  GPIO_Config.GPIO_Speed = GPIO_Speed_50MHz;
  GPIO_Init(SERVO_TILT_PWM, &GPIO_Config);

  /*
   * TIM2 Configuration: generate 2 PWM signals with 2 different duty cycles:
   * The TIM2CLK frequency is set to SystemCoreClock (Hz), to get TIM2 counter
   * clock at 24 MHz the Pre-scaler is computed as following:
   *  - Pre-scaler = (TIM2CLK / TIM2 counter clock) - 1
   * SystemCoreClock is set to 72 MHz for Low-density, Medium-density, High-density
   * and Connectivity line devices and to 24 MHz for Low-Density Value line and
   * Medium-Density Value line devices
   *
   * The TIM2 is running at 36 KHz: TIM2 Frequency = TIM2 counter clock/(ARR + 1) = 24 MHz / 666 = 36 KHz
   *     TIM2 Channel1 duty cycle = (TIM2_CCR1 / TIM2_ARR) * 100 = 50%
   *     TIM2 Channel2 duty cycle = (TIM2_CCR2 / TIM2_ARR) * 100 = 37.5%
   */

  // Compute the pre-scaler value
  prescalerValue = (uint16_t) (SystemCoreClock / 3000000) - 1;

  // Time base configuration
  TIM_TimeBaseStructInit(&TIM_TimeBaseStructure);
  TIM_TimeBaseStructure.TIM_Period = PWM_PERIOD;
  TIM_TimeBaseStructure.TIM_Prescaler = prescalerValue;
  TIM_TimeBaseStructure.TIM_ClockDivision = 0;
  TIM_TimeBaseStructure.TIM_CounterMode = TIM_CounterMode_Up;
  TIM_TimeBaseInit(TIM2, &TIM_TimeBaseStructure);

  TIM_OCStructInit(&TIM_OCInitStructure);
  TIM_OCInitStructure.TIM_OCMode = TIM_OCMode_PWM1;
  TIM_OCInitStructure.TIM_OCPolarity = TIM_OCPolarity_High;
  TIM_OCInitStructure.TIM_OutputState = TIM_OutputState_Enable;

  // PWM1 Mode configuration: Channel3 (Motor Left)
  TIM_OCInitStructure.TIM_Pulse = 0;
  TIM_OC3Init(TIM2, &TIM_OCInitStructure);
  TIM_OC3PreloadConfig(TIM2, TIM_OCPreload_Enable);

  // PWM1 Mode configuration: Channel4 (Motor Right)
  TIM_OCInitStructure.TIM_Pulse = 0;
  TIM_OC4Init(TIM2, &TIM_OCInitStructure);
  TIM_OC4PreloadConfig(TIM2, TIM_OCPreload_Enable);

  // PWM1 Mode configuration: Channel2 (Servo Tilt)
  TIM_OCInitStructure.TIM_Pulse = 0;
  TIM_OC2Init(TIM2, &TIM_OCInitStructure);
  TIM_OC2PreloadConfig(TIM2, TIM_OCPreload_Enable);
  servo_tilt_set(0x80);

  TIM_SelectOnePulseMode(TIM2, TIM_OPMode_Repetitive);
  TIM_ARRPreloadConfig(TIM2, ENABLE);
  TIM_Cmd(TIM2, ENABLE);
}

void motor_enable(int enable) {
  if (enable) {
    GPIO_SetBits(MOTOR_EN, MOTOR_EN_PIN);
    print_info("motor_enabled\n");
  } else {
    GPIO_ResetBits(MOTOR_EN, MOTOR_EN_PIN);
    print_info("motor_disabled\n");
  }
}

void motor_set_speed(int16_t speedLeft, int16_t speedRight) {
  if (speedLeft != lastSpeedLeft) {
    if (speedLeft > 0) {
      GPIO_ResetBits(MOTOR_LEFT_DIR, MOTOR_LEFT_DIR_PIN);
    } else {
      GPIO_SetBits(MOTOR_LEFT_DIR, MOTOR_LEFT_DIR_PIN);
    }
    TIM_SetCompare4(TIM2, speed_to_pwm_compare(speedLeft));
    lastSpeedLeft = speedLeft;
  }

  if (speedRight != lastSpeedRight) {
    if (speedRight > 0) {
      GPIO_SetBits(MOTOR_RIGHT_DIR, MOTOR_RIGHT_DIR_PIN);
    } else {
      GPIO_ResetBits(MOTOR_RIGHT_DIR, MOTOR_RIGHT_DIR_PIN);
    }
    TIM_SetCompare3(TIM2, speed_to_pwm_compare(speedRight));
    lastSpeedRight = speedRight;
  }
}

void servo_tilt_set(uint8_t val) {
  uint32_t t = val;
  if (t < 1) {
    t = 1;
  }
  t = t * (PWM_PERIOD / 256);
  if (t > (PWM_PERIOD - 32)) {
    t = PWM_PERIOD - 32;
  }
  TIM_SetCompare2(TIM2, t);
}

void servo_tilt_stop() {
  TIM_SetCompare2(TIM2, 0);
}

uint32_t speed_to_pwm_compare(int16_t speed) {
  uint32_t absSpeed = abs(speed);
  return absSpeed * (PWM_PERIOD / 128);
}

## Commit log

2013-06-06 motor controller
    [motorController.kicad_pcb, motorController.sch]
2013-06-10 v1 motor controller
    [motorController.kicad_pcb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]
2013-06-16 initial cut at virtual serial port
2013-07-03 working coms with android
    [motorController.sch]
2013-07-05 motor work startedg
2013-07-05 working motor pwm
2013-07-05 added command to turn on and off status led
2013-07-09 fixed pin numbering on motor controller
    [motorController.kicad_pcb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]
2013-07-13 motor bracket
    [HD-BK-IG.ipt]
2013-07-13 motor wheel assembly
    [HD-BK-IG-MotorBracket.ipt, MotorWheelAssembly.iam]
2013-07-14 basic robot
    [Human_5ft_9in.ipt, MainAssembly.iam, Nexus7.ipt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]
2013-07-14 support and materials
    [HD-BK-IG-MotorBracket.ipt, Human_5ft_9in.ipt, IG32P-Motor.ipt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]
2013-07-16 tablet mount
    [MainAssembly.iam, Nexus7.ipt, Servo-Horn.STEP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]
2013-08-02 add pullups to motorcontroller
    [motorController.kicad_pcb, motorController.sch]
2013-08-02 main board work
    [batteryCharger.sch, main.sch, power.sch]
2013-08-02 increate pwm frequency
2013-08-09 initial cut at speed alg
2013-08-10 main schematic work
    [android.sch, main.sch, motorControllers.sch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]
2013-08-14 schematic updates
    [android.sch, main.sch, motorControllers.sch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]
2013-08-14 added servo support
    [main.sch]
2013-08-14 battery voltage
    [main.sch]
2013-08-20 updates to mechanical
    [CircuitBoard.ipt, HD-BK-IG-MotorBracket.ipt, IG32P-Motor.ipt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]
2013-08-21 update schematic
    [android.sch, main.sch, motorControllers.sch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]
2013-08-27 initial new.mod
    [android.sch, main.kicad_pcb, power.sch]
2013-08-27 2-pin header
    [android.sch, main.kicad_pcb, main.sch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]
2013-08-27 more pcb work
    [main.kicad_pcb]
2013-08-27 support update from kicad-library
2013-08-27 update net
    [android.sch, main.sch, motorControllers.sch]
2013-08-29 more footprints
    [main.kicad_pcb]
2013-08-30 new packages
    [main.kicad_pcb]
2013-08-30 new pcb
    [main.kicad_pcb]
2013-09-02 layout no unconnected
    [main.kicad_pcb, motorControllers.sch, power.sch]
2013-09-03 added border and larger traces
    [main.kicad_pcb]
2013-09-03 moved labels. increased power widths
    [main.kicad_pcb]
2013-09-03 power track width, ground plane connects
    [main.kicad_pcb]
2013-09-03 moved motor controller to breakout boards
    [motorController.kicad_pcb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]
2013-09-03 v1 update
    [main.kicad_pcb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]
2013-09-03 rotated jtag header
    [main.kicad_pcb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]
2013-09-03 v1 final
    [main.kicad_pcb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]
2013-09-10 add kicad-library as git subtree
2013-09-10 fix save and update kicad-library to use subtree
2013-09-23 calculations for battery charger
    [main.kicad_pcb, main.sch, power.sch]
2013-09-29 changed silk size
    [android.sch, main.kicad_pcb, main.sch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]
2013-10-06 fixed 'O' bridge to be printable
    [TabletMount-Mast-Left.ipt, TabletMount-Mast-Right.ipt]
2013-10-06 redesign mount
    [MainAssembly.iam, Servo.ipt, ServoMount.ipt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]
2013-10-06 removed unused parts
    [MainAssembly.iam, ServoMount.ipt, TableMount-Base.ipt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]
2013-10-06 added mast tolerance
    [MainAssembly.iam, TableMount-Holder.ipt, TabletMount-Mast-Left.ipt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]
2013-10-06 Created holder control part
    [MainAssembly.iam, TableMount-Base.ipt, TableMount-Holder.ipt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]
2013-10-09 increase power track thickness
    [android.sch, main.kicad_pcb, main.sch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]
2013-10-12 handle non printable characters
2013-10-13 battery latch
    [BatteryLatch-Latch.ipt, BatteryLatch-Lower.ipt, BatteryLatch-Outer.ipt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]
2013-10-16 refactor and added battery level
2013-11-13 stop servo after x time
2013-11-21 changed to using sockets on Android instead of web sockets
2013-11-22 cut speed in half
2014-08-08 add pdf of schematic
2014-08-08 add schematic link
